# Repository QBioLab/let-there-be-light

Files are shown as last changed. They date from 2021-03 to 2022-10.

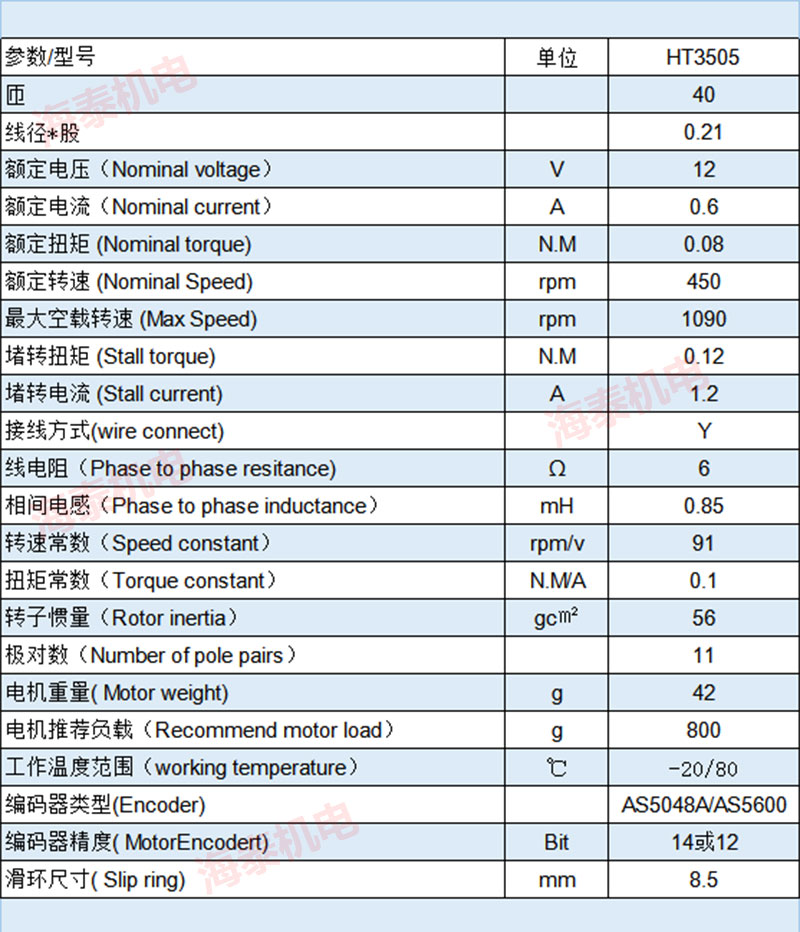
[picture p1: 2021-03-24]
Mechanism/datasheet/HT3505-2.jpg

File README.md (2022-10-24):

# Let there be light
Track and light mouse

## Control and Computing Unit with Khadas 控制和运算单元
Target: enable to remote controll, graph interface, error handle

Khadas VIM3 don't shop the kernel with usbtmc and i2c mux driver, so I
[rebuild kernel](https://docs.khadas.com/vim3/HowToUpgradeTheKernel.html)
inside [fenix's docker](https://github.com/khadas/fenix).
The usbtmc and i2c mux are package as module, I load [module automatic with systemd](https://wiki.archlinux.org/title/Kernel_module)
by add `usbtmc` and `i2c_mux_pca954x` to `/etc/modules-load.d/modules.conf`.

Only one USB bus is exported in VIM3, I try to use orignal M.2 port as PCI-e
port. I install ADT-Link's [M.2 NVMe to PCIe X1 extender](http://www.adtlink.cn/en/product/R41.html)
on Khadas M.2 extender board, then a PCIe Card(VIA VL805). The PCIe card is
power by sperated 5V. But system only reconginze this
card as USB2 bus. Why? May I also feed 12v pin. Once I mount USB3 device,
system will reboot. 

TODO: assign fixed camera path to specifical usb port. Device info could get
from `udevadm info -a -p  $(udevadm info -q path -n /dev/video0)`

TODO: organize output information
TODO: send command to power supply then release and return.

Build GUI in QT. 

Reference:
- [PyQtGraph library](https://github.com/pyqtgraph/pyqtgraph)
- [Assign fixed usb port name](https://www.freva.com/2019/06/20/assign-fixed-usb-port-names-to-your-raspberry-pi/)
- [How to bind v4l2 USB cameras to the same device names even after reboot?](https://unix.stackexchange.com/questions/77170/how-to-bind-v4l2-usb-cameras-to-the-same-device-names-even-after-reboot)
- [Convert M.2 to PCI-e in VIM3](https://forum.khadas.com/t/pci-e-card-power-supply/12122)
- [WiringPi-Python on VIM](https://docs.khadas.com/zh-cn/vim3/HowToUseWiringPi-Python.html)
- [Change Logo](https://docs.khadas.com/zh-cn/vim3/HowToChangeBootLogo.html)
- [Autostart login tty1 and execute command](https://unix.stackexchange.com/questions/44288/run-gui-application-on-startup)
- [renesas-UPD720201-usb3](https://pipci.jeffgeerling.com/cards_usb/renesas-UPD720201-usb3-6amlifestyle.html)

## Gimbal design and setting 云台设计
Before run SimpleBGC in khadas, please install `librxtx-java`

calibration design

```
|--------------------------|
| Camera & Gimbal Geometry |
|--------------------------|
|  O----> x                |
|  |                       |
| \|/     |--------|       |
|  y      | CAMERA |       |
|         |--------|       |
|                          |
|         |--------| +90   |
|         | GIMBAL | /|\   |
|         |--------|  |    |
|                0<---+yaw |
|--------------------------|
```

<<<<<<< HEAD
coordintiona transformation.
=======

>>>>>>> c09984db9b780412b9dba95ce789de024a3bc1f3

## Tracker Design
Color and movement

## ISSUSE & TODO 现存问题
+ offline test: gimbal rotate in preload sequence and saved video
+ add laser power switch in GUI
+ 微弱信号识别及过滤干扰目标: detect moving region
+ send poweroff command to motor after closing  
+ add force exit function, such as reboot?

## Ref 参考
https://superuser.com/questions/497933/50-usb-webcams-in-a-single-computer-is-that-really-possible

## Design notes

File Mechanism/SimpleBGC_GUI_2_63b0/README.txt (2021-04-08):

WINDOWS users: just run exe file

MAC OS users:  GUI uses a serial communication, that needs to create a lock file. 
To allow it, you should to do the following steps:
1. Start terminal (navigate to /Applications/Utilities and double click on Terminal)
2. Make folder "/var/lock" by command: sudo mkdir /var/lock
3. Change permissions by command: sudo chmod 777 /var/lock
4. Allow to run non-signed applications in  System Preferences > Security & Privacy > 
	General > Allow Applications downloaded from: Anywhere  (see http://d.pr/i/9fAm )

LINUX users: 
run.sh

ALL SYSTEMS: 

Special system drivers may be required. Check the recomendations of the seller of your board,
or try general drivers that may suit:
	
	FTDI http://www.ftdichip.com/Drivers/VCP.htm
	CP2102 http://www.silabs.com/products/mcu/pages/usbtouartbridgevcpdrivers.aspx

CONSOLE MODE

In this mode Java console is shown, that may be usefull for debugging
Start application by running script "run_console.bat" (or create similar script for your operating sysytem).

COMMAND-LINE MODE

There are several usefull commands that can be run in command-line mode (without opening the main interface window).
Execute "sbgc_cmd.bat" and it will print the usage prompt.

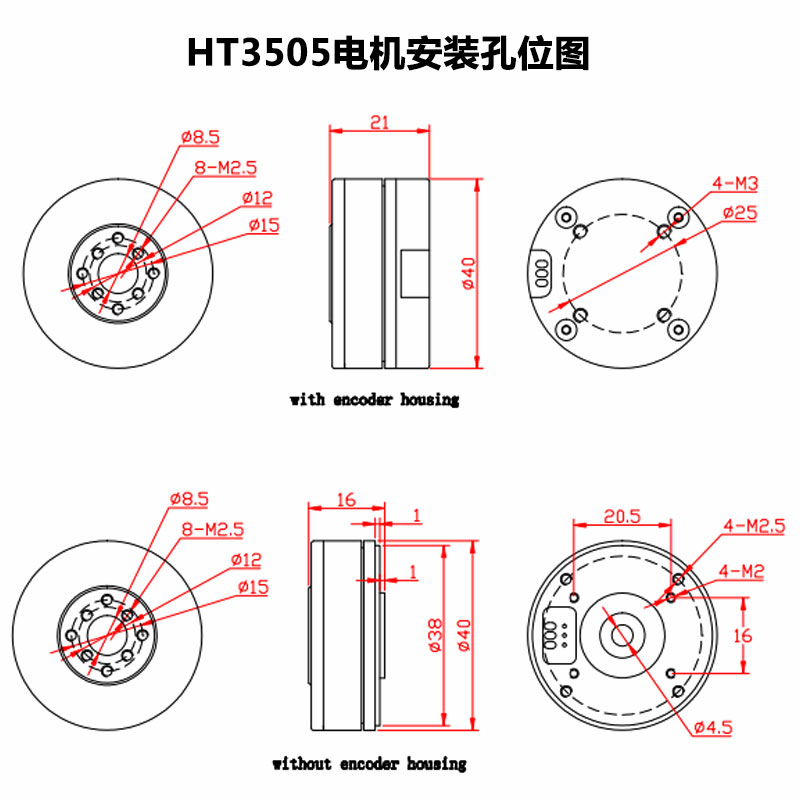
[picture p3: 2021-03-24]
Mechanism/datasheet/HT3505.jpg

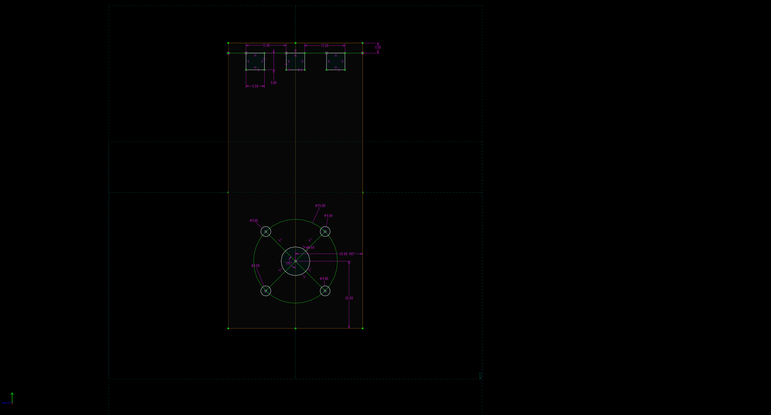
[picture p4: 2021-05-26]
Mechanism/gimbal-arm2-pitch.png

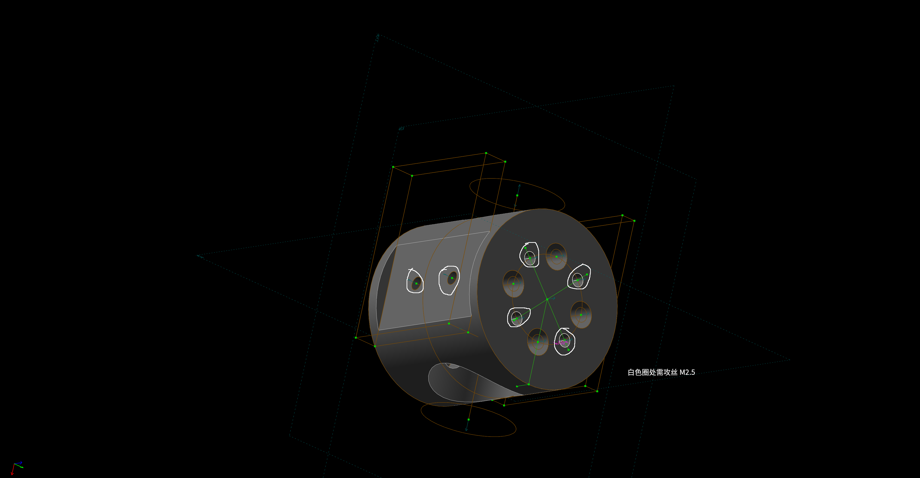
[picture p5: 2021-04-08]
Mechanism/CNC/gimbal-gun2-攻丝标注.png

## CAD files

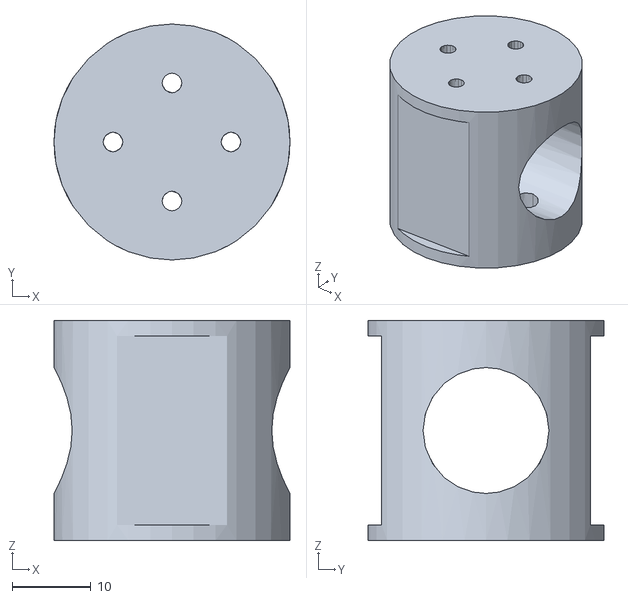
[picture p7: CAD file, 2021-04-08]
Mechanism/3d_printer/gimbal-gun2.stl
30.0 x 30.0 x 28.0

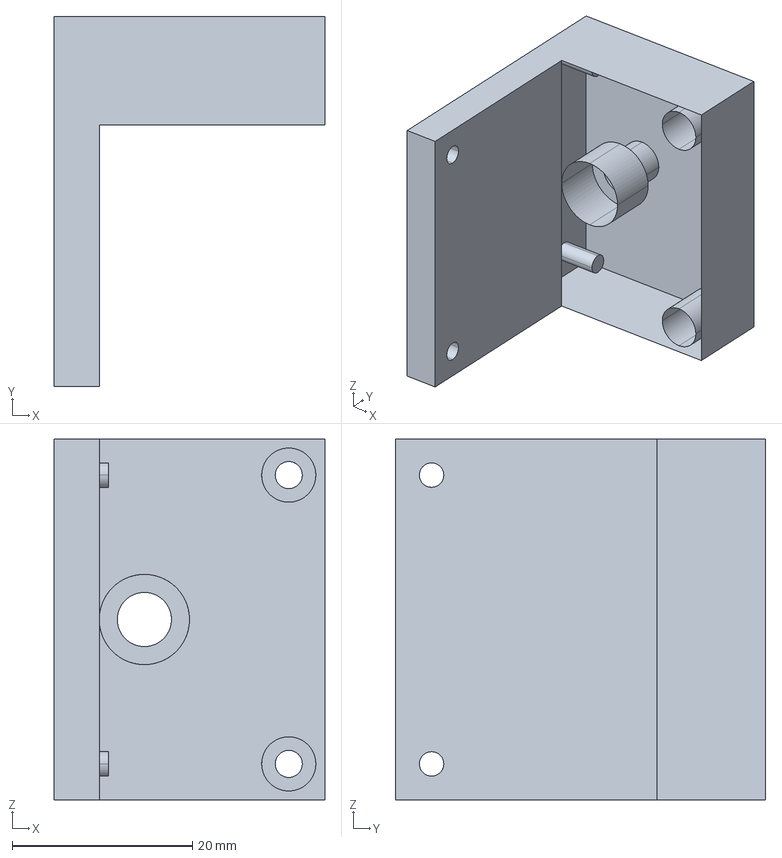
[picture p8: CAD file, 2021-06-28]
Mechanism/CNC/rightAngle.step
30.0 x 41.0 x 40.0 mm

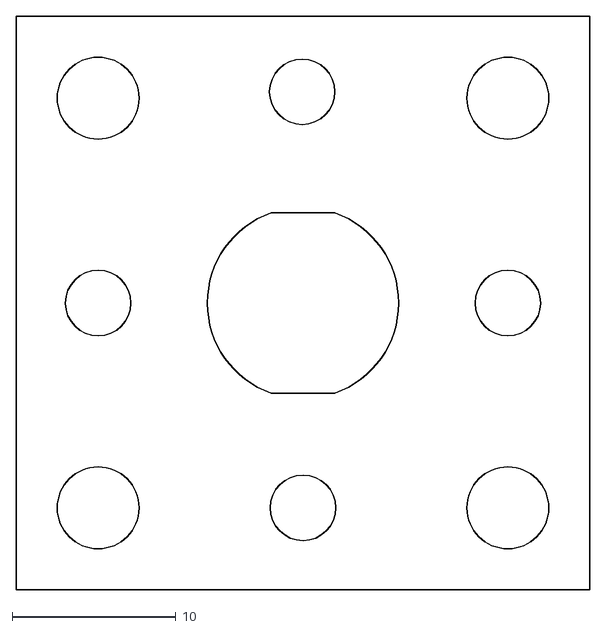
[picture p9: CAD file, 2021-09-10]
Mechanism/Cutting/PluginSet.dxf
35.0 x 35.0

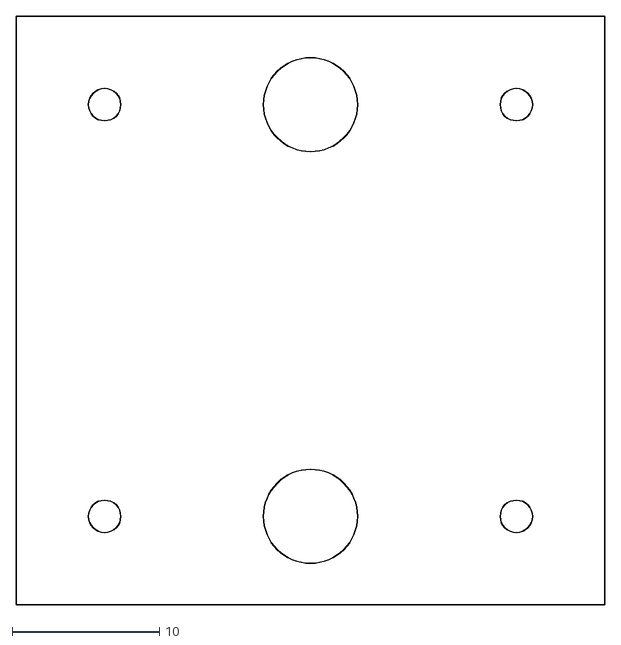
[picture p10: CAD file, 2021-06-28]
Mechanism/摄像头铝型材架.dxf
40.0 x 40.0

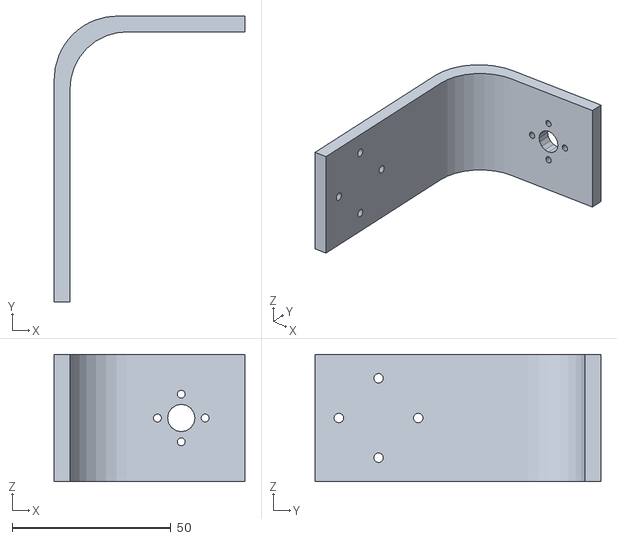
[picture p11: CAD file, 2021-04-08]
Mechanism/3d_printer/gimbal-arm.stl
60.0 x 90.0 x 40.0

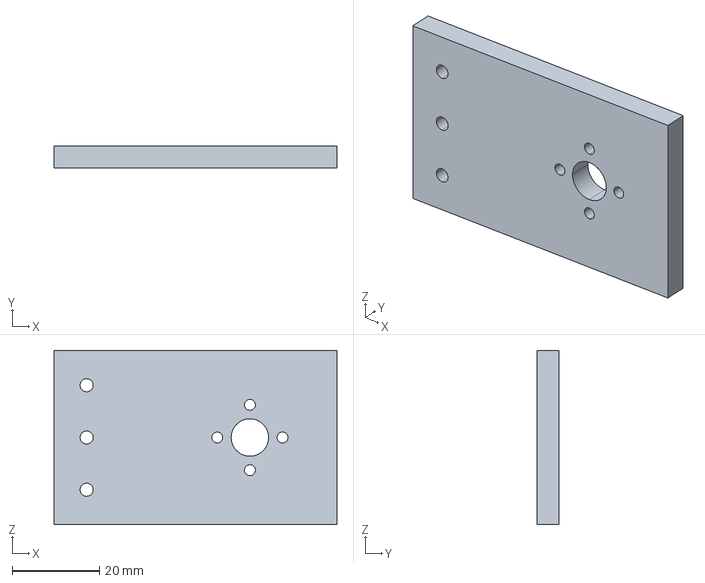
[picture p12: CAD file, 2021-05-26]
Mechanism/CNC/gimbal-arm-yaw-20210416.step
65.0 x 5.00 x 40.0 mm

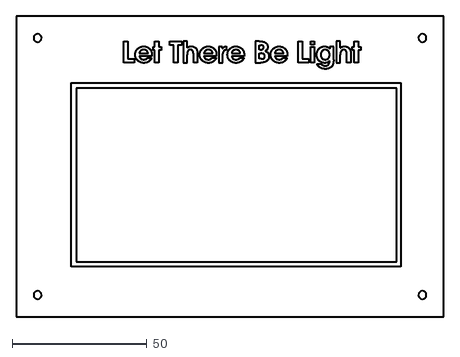
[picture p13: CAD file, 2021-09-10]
Mechanism/Cutting/TouchScreenSet.dxf
159.0 x 111.5

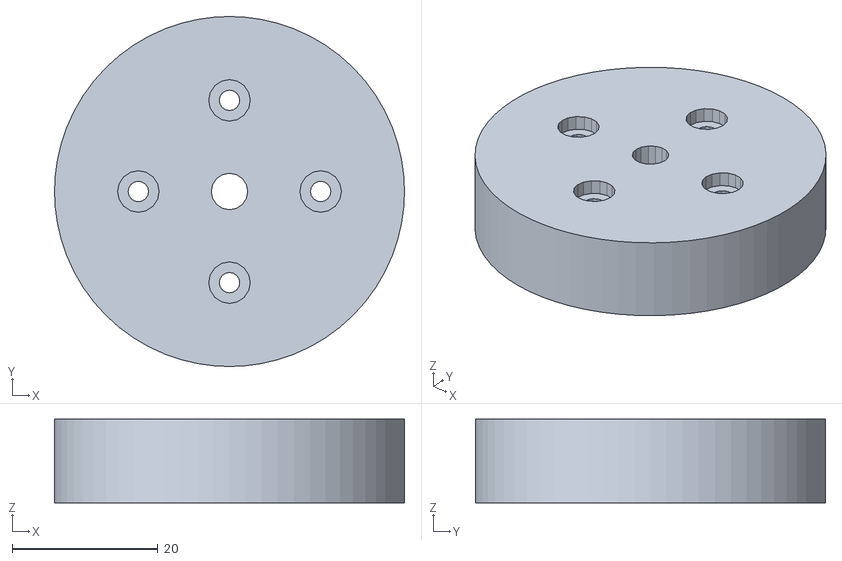
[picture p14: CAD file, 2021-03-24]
Mechanism/3d_printer/gimbal-header.stl
48.0 x 48.0 x 11.5

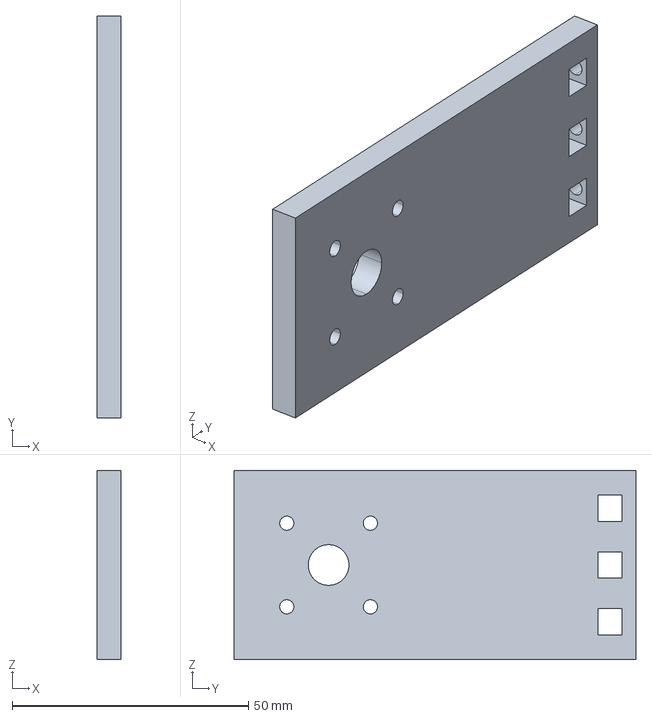
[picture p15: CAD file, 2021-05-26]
Mechanism/CNC/gimbal-arm2-pitch-20210427.step
5.00 x 85.0 x 40.0 mm

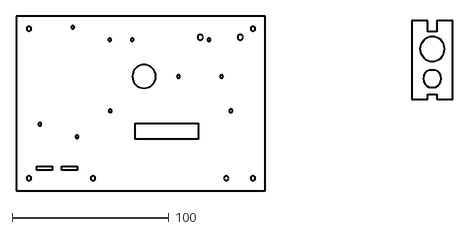
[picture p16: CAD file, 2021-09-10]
Mechanism/Cutting/ComputerCase.dxf
278.5 x 111.5

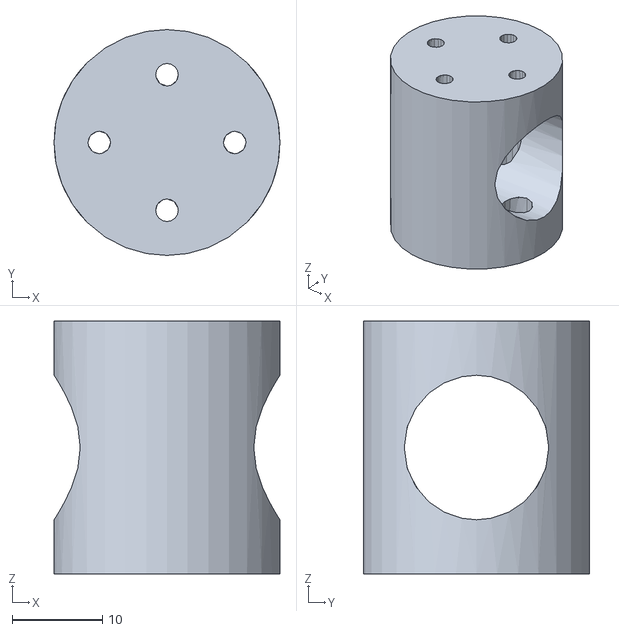
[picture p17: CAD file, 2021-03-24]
Mechanism/3d_printer/gimbal-gun.stl
25.0 x 25.0 x 28.0

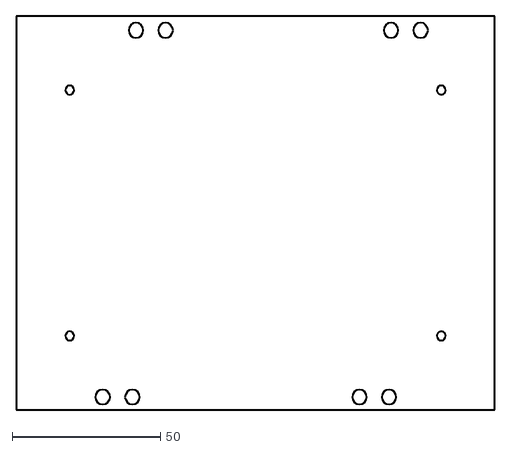
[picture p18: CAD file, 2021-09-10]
Mechanism/Cutting/powersupplysheet.dxf
161.5 x 133.0

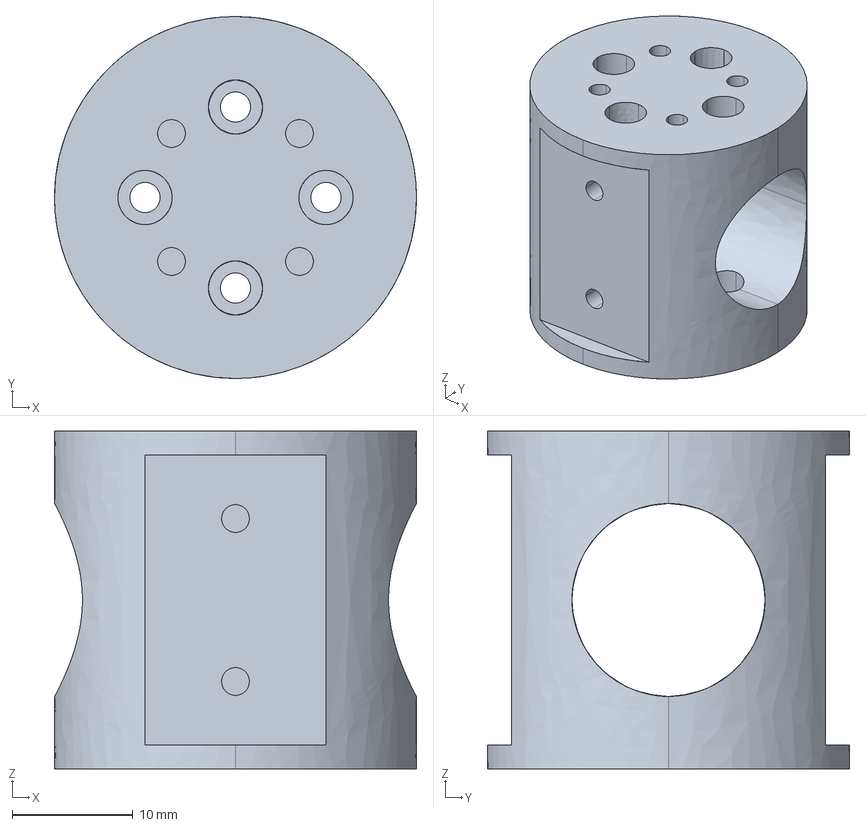
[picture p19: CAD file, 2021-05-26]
Mechanism/CNC/gimbal-gun2-20210416.step
30.0 x 30.0 x 28.0 mm

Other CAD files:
Mechanism/CNC/gimbal-arm-pitch-20210416.step
Mechanism/CNC/gimbal-header2-20210428.step
Mechanism/CNC/gimbal-header2-20210416.step
Mechanism/CNC/gimbal-gun2.step
Mechanism/CNC/gimbal-arm2.step
Mechanism/CNC/gimbal-header2.step

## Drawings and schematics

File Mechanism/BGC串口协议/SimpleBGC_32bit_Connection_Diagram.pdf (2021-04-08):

# BATTERY

# SimpleBGC 3.0 (32bit) connection diagram

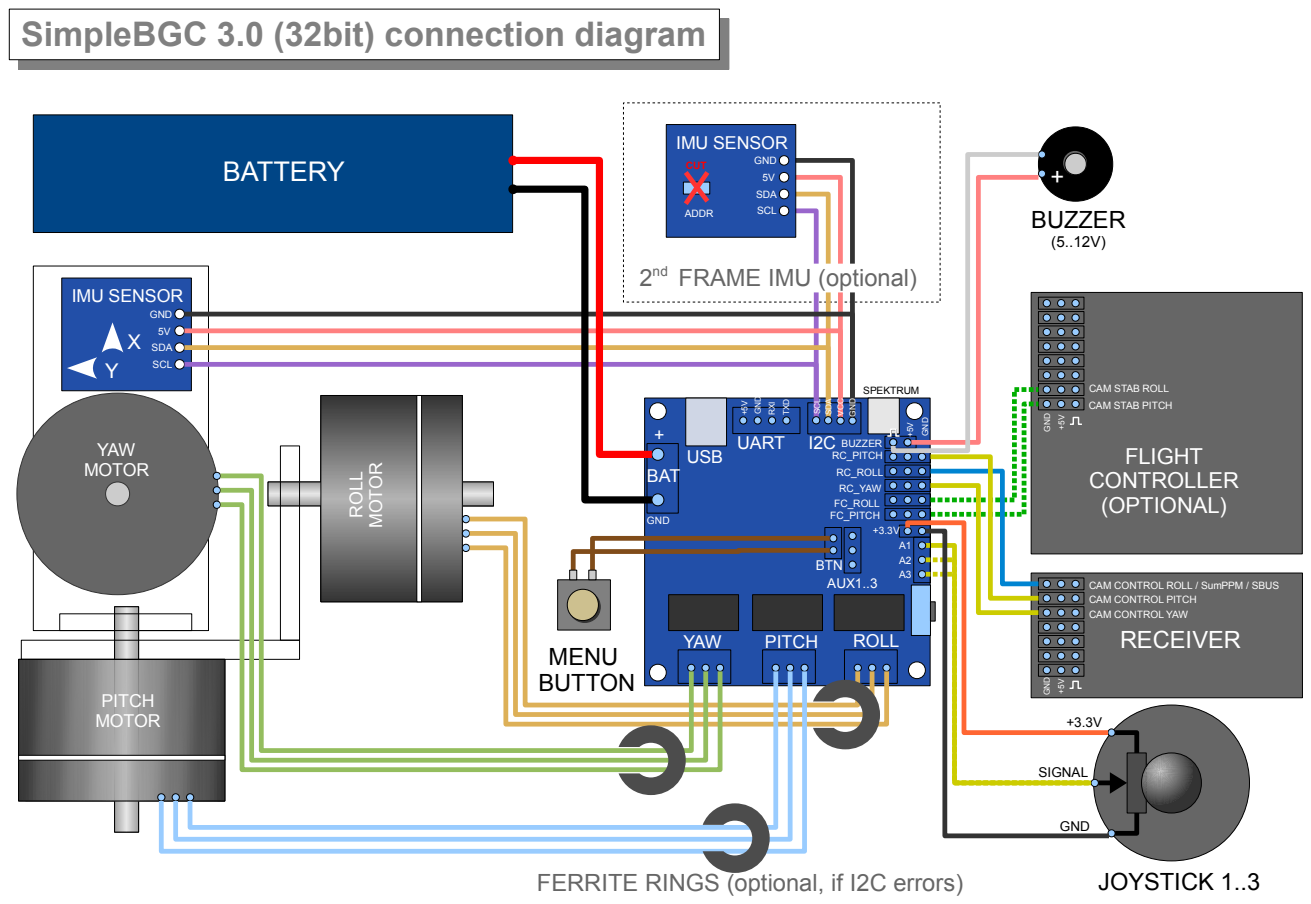
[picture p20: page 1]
UART; PITCH; ROLL; BAT; GND; FC_ROLL FC_PITCH; RC_ROLL; RC_PITCH; RXI; TXD; SCL; SDA; VCC; PITCH MOTOR; YAW MOTOR; IMU SENSOR; MENU BUTTON; JOYSTICK 1..3; SIGNAL; YAW; ADDR; CUT; BTN; RC_YAW; BUZZER; USB; AUX1..3; SPEKTRUM

nd FRAME IMU (optional)

CAM STAB ROLL
CAM STAB PITCH
FLIGHT
CONTROLLER
(OPTIONAL)

CAM CONTROL ROLL / SumPPM / SBUS
CAM CONTROL PITCH
CAM CONTROL YAW
RECEIVER

FERRITE RINGS (optional, if I2C errors)

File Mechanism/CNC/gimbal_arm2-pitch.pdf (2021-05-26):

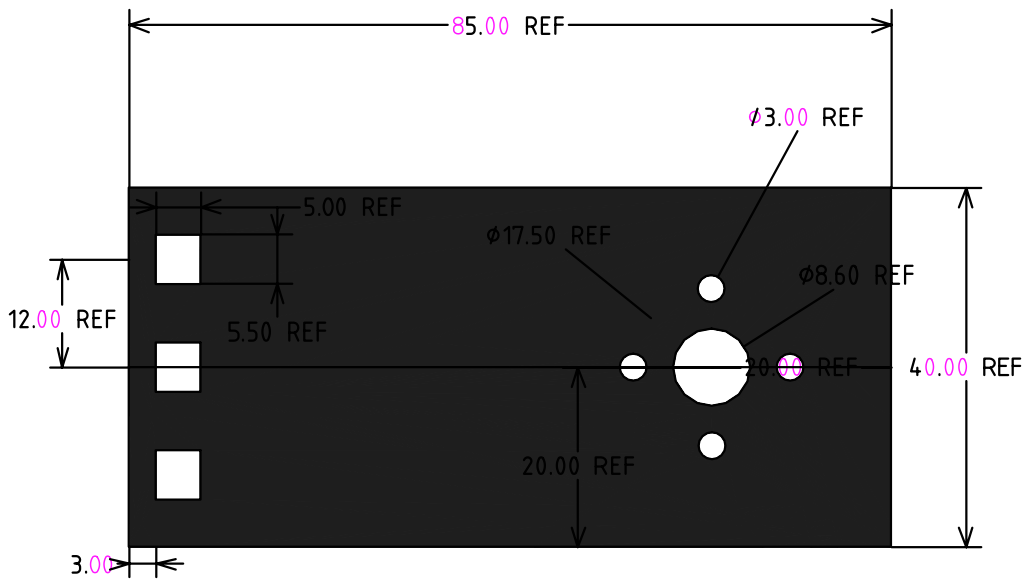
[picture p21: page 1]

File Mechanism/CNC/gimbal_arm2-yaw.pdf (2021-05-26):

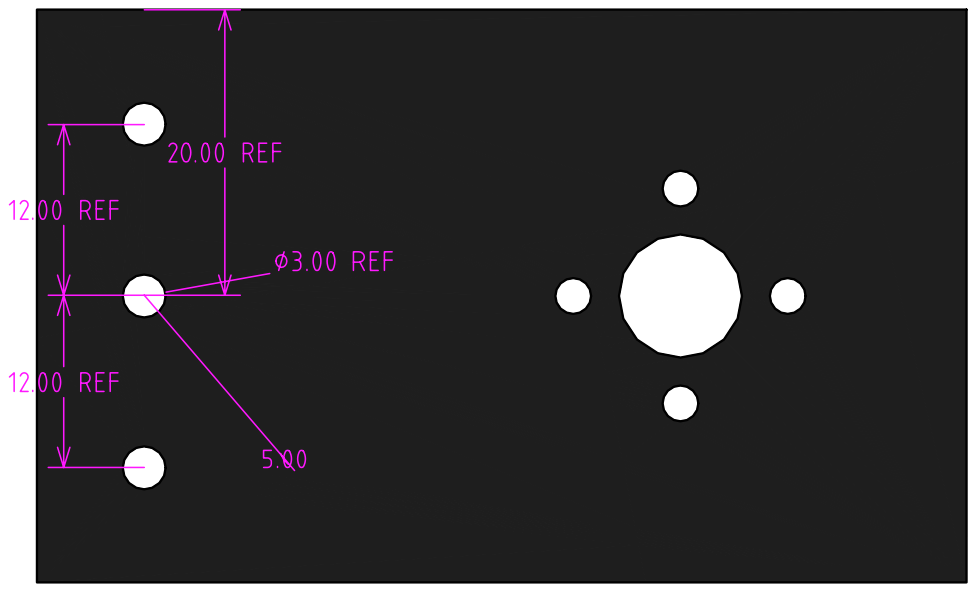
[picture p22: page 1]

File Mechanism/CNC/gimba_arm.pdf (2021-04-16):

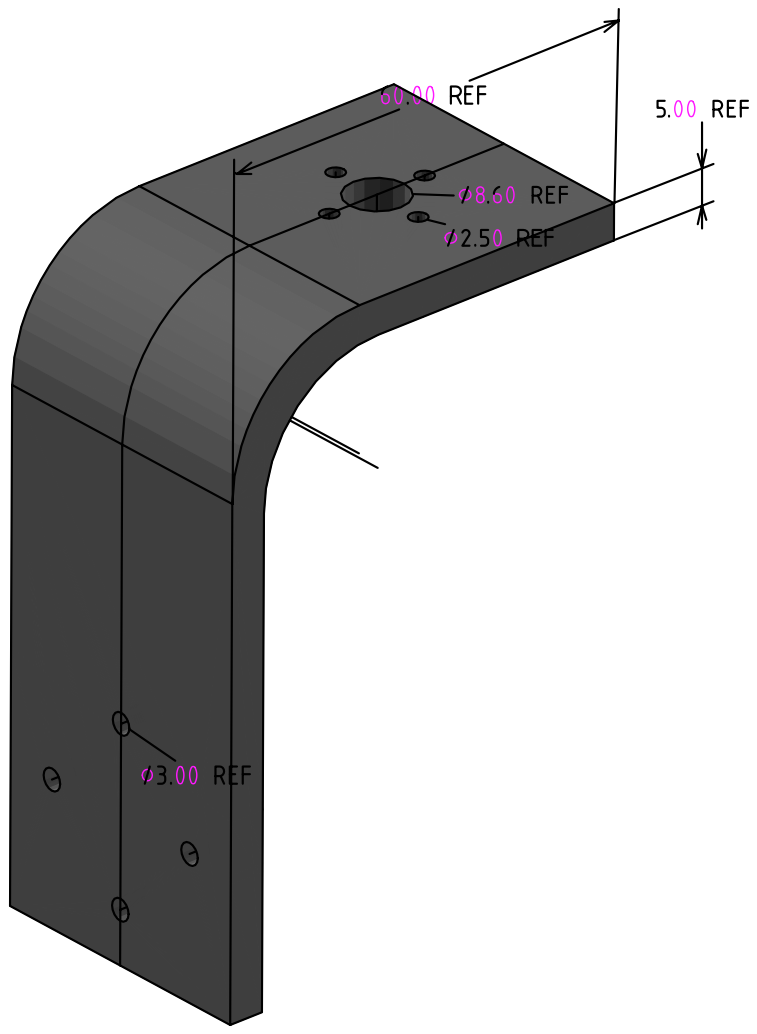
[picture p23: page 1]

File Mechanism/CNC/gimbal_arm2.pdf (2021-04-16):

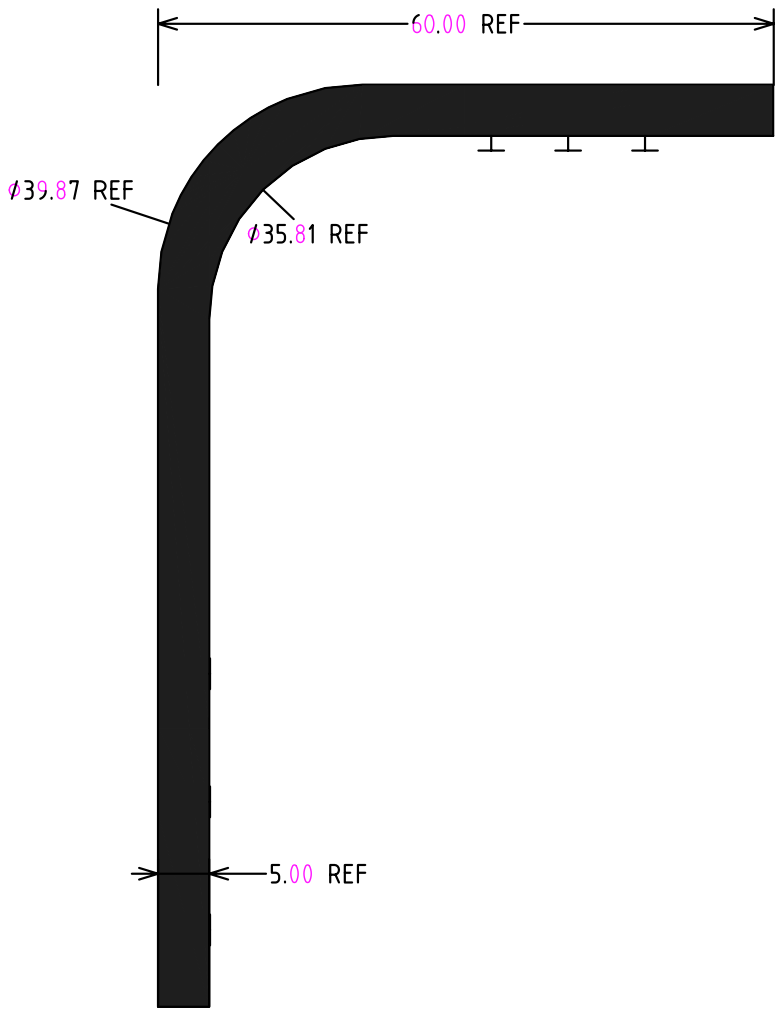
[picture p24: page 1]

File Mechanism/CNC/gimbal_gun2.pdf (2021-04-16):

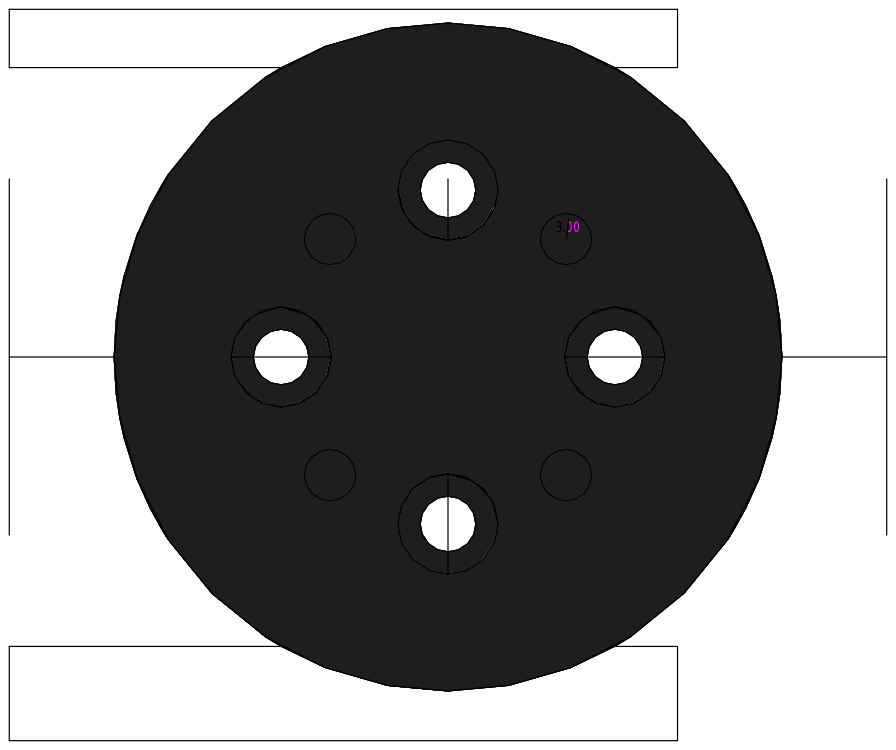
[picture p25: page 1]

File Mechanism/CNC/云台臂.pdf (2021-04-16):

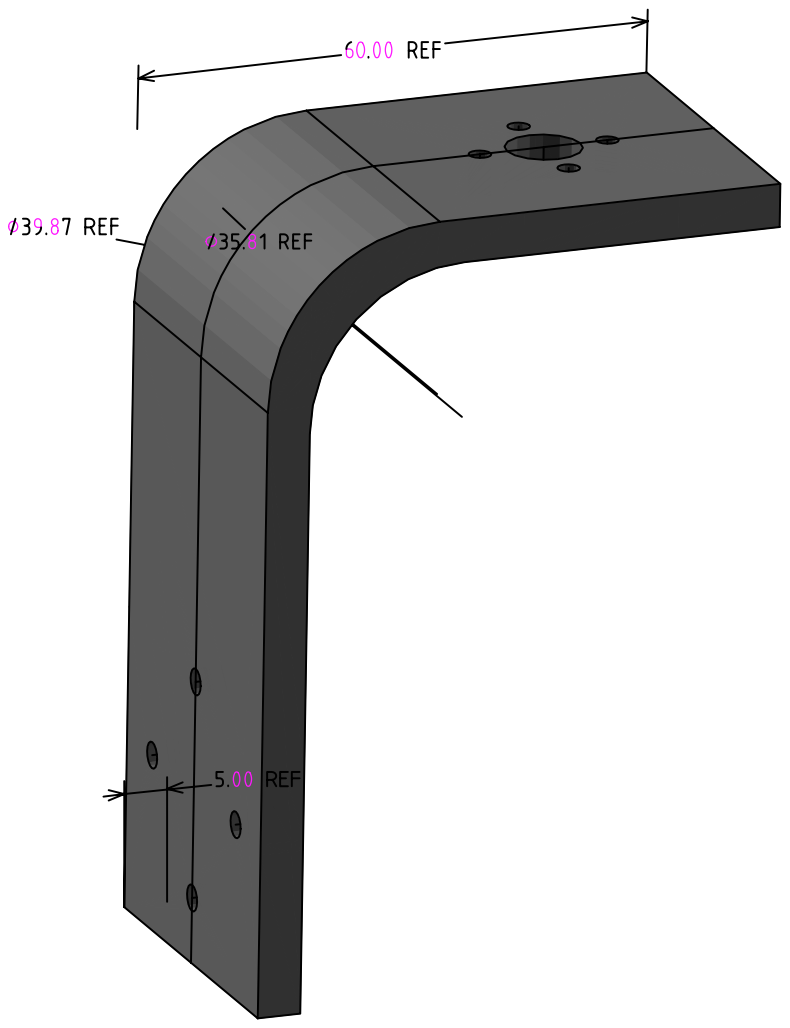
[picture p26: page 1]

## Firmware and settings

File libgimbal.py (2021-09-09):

import sys
import serial
import struct
from collections import namedtuple

"""
v0.1 first version
"""

# outgoing CMD_CONTROL - control gimbal movement
ControlData = namedtuple(
    'ControlData',
    'roll_mode pitch_mode yaw_mode roll_speed roll_angle \
     pitch_speed pitch_angle yaw_speed yaw_angle')
AngleData = namedtuple(
    'AngleData',
    'imu_roll_angle target_roll_angle target_roll_speed \
     imu_pitch_angle target_pitch_angle target_pitch_speed \
     imu_yaw_angle target_yaw_angle target_yaw_speed')
Message = namedtuple(
    'Message',
    'start_character command_id payload_size header_checksum \
    payload payload_checksum')

MOTOR_UNIT = 0.02197265625 # 720/32768


class gimbal:
    def __init__(self, PORT):
        self.PORT = PORT
        self.connected = False
        self.connect()
        
    def pack_control_data(self, control_data: ControlData) -> bytes:
        return struct.pack('<BBBhhhhhh', *control_data)

    def create_message(self, command_id: int, payload: bytes) -> Message:
        payload_size = len(payload)
        return Message(start_character=ord('>'),
              command_id=command_id,
              payload_size=payload_size,
              header_checksum=(command_id + payload_size) % 256,
              payload=payload,
              payload_checksum=sum(payload) % 256)

    def pack_message(self, message: Message) -> bytes:
        message_format = '<BBBB{}sB'.format(message.payload_size)
        return struct.pack(message_format, *message)


    def unpack_message(self, data: bytes, payload_size: int) -> Message:
        message_format = '<BBBB{}sB'.format(payload_size)
        return Message._make(struct.unpack(message_format, data))

    def read_message(self, connection: serial.Serial, payload_size: int) -> Message:
        # 5 is the length of the header + payload checksum byte
        # 1 is the payload size
        response_data = connection.read(5 + payload_size)
        #print('received response', response_data)
        return self.unpack_message(response_data, payload_size)

    def park_gimbal(self):
        self.rotate_gimbal(70, 0)

    def cal_motor_angle(self, angle):
        motor_angle = int(angle/MOTOR_UNIT)
        return motor_angle

    def rotate_gimbal(self, pitch_angle, yaw_angle):
        pitch_motor_angle = self.cal_motor_angle(pitch_angle)
        yaw_motor_angle = self.cal_motor_angle(yaw_angle)
        self.rotate_gimbal_in_motor_angle(pitch_motor_angle, yaw_motor_angle)

    def rotate_gimbal_in_motor_angle(self, pitch_motor_angle, yaw_motor_angle):
        CMD_CONTROL = 67
        control_data = ControlData(roll_mode=0, roll_speed=0, roll_angle=0,
                               pitch_mode=2, pitch_speed=32767, pitch_angle=pitch_motor_angle,
                               yaw_mode=5, yaw_speed=32767, yaw_angle=yaw_motor_angle)
        packed_control_data = self.pack_control_data(control_data)
        message = self.create_message(CMD_CONTROL, packed_control_data)
        packed_message = self.pack_message(message)
        self.connection.write(packed_message)
        # message = self.read_message(self.connection, 1)
        #print('received confirmation:', message)
        # print('confirmed command with ID:', ord(message.payload))

    def rotate_gimbal_rel(self, pitch_angle, yaw_angle):
        CMD_CONTROL = 67
        control_data = ControlData(roll_mode=0, roll_speed=0, roll_angle=0,
                               pitch_mode=5, pitch_speed=32767, pitch_angle=pitch_angle,
                               yaw_mode=5, yaw_speed=32767, yaw_angle=yaw_angle)
        packed_control_data = self.pack_control_data(control_data)
        message = self.create_message(CMD_CONTROL, packed_control_data)
        packed_message = self.pack_message(message)
        self.connection.write(packed_message)
        message = self.read_message(self.connection, 1)
        print('received confirmation:', message)
        print('confirmed command with ID:', ord(message.payload))

    def get_angles(self):
        CMD_GET_ANGLES = 73
        message = self.create_message(CMD_GET_ANGLES, b'')
        packed_message = self.pack_message(message)
        self.connection.write(packed_message)
        message = self.read_message(self.connection, 18) # 2*3*3
        return AngleData._make(struct.unpack('hhhhhhhhh', message.payload))

    def get_frame_heading_angle(self):
        """Get Frame Heading Angle
        |NUM_PARAMS 1u| PARAM_ID 1u|
        Uints: 1 degrees
        """
        CMD_GET_ADJ_VARS_VAL = 64
        FRAME_HEADING_ANGLE = 37
        message = self.create_message(CMD_GET_ADJ_VARS_VAL, 
                struct.pack('BB', 1, FRAME_HEADING_ANGLE))
        packed_message = self.pack_message(message)
        self.connection.write(packed_message)
        message = self.read_message(self.connection, 6) # 1u+1u+4b, 0.1 degrees
        data = struct.unpack('BBbbbb', message.payload) # eg. (1, 37, -1, 127, 0 ,0)
        return struct.unpack('BBbbbb', message.payload)
        #return (data[2]*1000 + (data[2]/abs(data[2]))*data[3])*0.1

    def set_frame_heading_angle(self, par1, par2, par3, par4):
        CMD_SET_ADJ_VARS_VAL = 31
        FRAME_HEADING_ANGLE = 37
        message = self.create_message(CMD_SET_ADJ_VARS_VAL, 
                struct.pack('BBbbbb', 1, FRAME_HEADING_ANGLE, par1, par2, par3, par4))
        packed_message = self.pack_message(message)
        self.connection.write(packed_message)
        message = self.read_message(self.connection, 1) 
        print('confirmed command with ID:', ord(message.payload))

    def connect(self):
        if self.connected == False:
            try:
                self.connection = serial.Serial(self.PORT, baudrate=115200, timeout=10)
                self.connected = True
            except Exception as error:
                print("Serial error, please check serial port")
                print("Detail: ", error)
                sys.exit()

    def disconnect(self):
        if self.connected == True:
            self.connection.close()
            self.connected = False
            print("Disconnect gimbal")

if __name__ == '__main__':
    gimbal_serial_name = "/dev/ttyGIMBAL1"
    if len(sys.argv) == 2 :
        gimbal_serial_name = sys.argv[1]
    gimbal_run = gimbal(gimbal_serial_name)
    gimbal_run.park_gimbal()

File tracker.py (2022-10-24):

import os
import time
import cv2 as cv
import numpy as np

"""
detecte mouse and laser point
V0.1 orignal work by zhangyi
V0.2 package to class
"""

FAIL = 0 # lost camera connection
MOVE = 1 # apply track
PARK = 2 # park pointer
LOST = 3 # lost mouse
IGNO = 4 # ignore tracking result

class MouseTracker:
    def __init__(self, camera_addr, roi):
        # initialize camera
        self.camera_addr = camera_addr
        try:
            self.camera = cv.VideoCapture(self.camera_addr)
        except Exception as error:
            print("Fail to open camera", self.camera_addr,":", error)
        # use MJPG to low cost of USB bandwidth 
        # ref: https://github.com/opencv/opencv/issues/9540
        self.camera.set(cv.CAP_PROP_FRAME_WIDTH, 640)
        self.camera.set(cv.CAP_PROP_FRAME_HEIGHT, 480)
        self.camera.set(cv.CAP_PROP_FPS, 25)
        self.camera.set(cv.CAP_PROP_AUTO_EXPOSURE, 1) # 1 for manual mode
        self.camera.set(cv.CAP_PROP_EXPOSURE, 100)
        #cam.set(cv.CAP_PROP_AUTO_WB, 0)
        fourcc = cv.VideoWriter_fourcc(*"MJPG")
        self.camera.set(cv.CAP_PROP_FOURCC, fourcc)
        # initialize video recorder
        self.save_moive = False
        self.save_fps = 5
        self.save_dir = "/dev/null"
        self.roi = roi  #[y0, y1, x0, x1]
        self.erode1 = 5
        self.centroid_y = self.centroid_x = 0
        self.last_centroid_y = self.last_centroid_x = 0
        self.count = 0
        self.last_time= time.time()

    def detecte_laser(self, frame):
        blue_mask = cv.inRange(frame, (0, 0, 220), (255, 255, 255)) 
        #return centroid_blue_x, centroid_blue_y

    def mask_red(self, hsv_frame):
        """HSV 遮罩"""
        hsv_h_range = [0, 10, 156, 180]
        hsv_s_range = [100, 250]
        hsv_v_range = [50, 200]
        lower_hsv0 = np.array([hsv_h_range[0], hsv_s_range[0], hsv_v_range[0]])
        upper_hsv0 = np.array([hsv_h_range[1], hsv_s_range[1], hsv_v_range[1]])
        lower_hsv1 = np.array([hsv_h_range[2], hsv_s_range[0], hsv_v_range[0]])
        upper_hsv1 = np.array([hsv_h_range[3], hsv_s_range[1], hsv_v_range[1]])
        mask0 = cv.inRange(hsv_frame, lower_hsv0, upper_hsv0)
        mask1 = cv.inRange(hsv_frame, lower_hsv1, upper_hsv1)
        mask_red = mask0 + mask1
        return mask_red

    def set_mask_red(self):
        """Set mask parameters"""
        print("Set HSV filter parameters")
    
    def mask_red_bgr(self, procession):
        """BGR 遮罩"""
        lower_bgr = np.array([90, 110, 180])
        upper_bgr = np.array([120, 150, 240])
        mask_red_bgr = cv.inRange(procession, lower_bgr, upper_bgr)
        return mask_red_bgr

    def set_erode1(self, erode1):
        self.erode1 = erode1

    def morphology_process(self, mask, erode1):
        """形态学处理"""
        morphology = cv.erode(mask, cv.getStructuringElement(cv.MORPH_ELLIPSE, \
                (self.erode1, self.erode1)))
        morphology = cv.dilate(morphology, cv.getStructuringElement(cv.MORPH_ELLIPSE, (30, 30)))
        morphology = cv.erode(morphology, cv.getStructuringElement(cv.MORPH_ELLIPSE, (20, 20)))
        morphology = cv.dilate(morphology, cv.getStructuringElement(cv.MORPH_ELLIPSE, (10, 10)))
        return morphology

    def track_mouse(self):
        """track red spot on mouse frame by frame
        return: result, position, image 
        """
        ret, frame = self.camera.read()
        if not ret:
            return FAIL, None, None
        #[y0:y1, x0:x1]
        procession = frame[self.roi[0]: self.roi[1], self.roi[2]: self.roi[3]]
        self.save_data(procession)

        #HSV 遮罩
        hsv_frame = cv.cvtColor(procession, cv.COLOR_BGR2HSV)
        mask = self.mask_red(hsv_frame)
        if np.all(mask == 0):
            self.count = self.count + 1
            print('mask = None', self.count)
            if self.count >= 5000:
                self.count = 0
                #return PARK, None, procession
            return LOST, None, procession

        #形态学处理
        morphology = self.morphology_process(mask, self.erode1)
        if np.all(morphology == 0):
            self.count = self.count + 1
            print('morphology = None', self.count)
            if self.count >= 5000:
                self.count = 0
                #return PARK, None, procession
            return LOST, None, procession

        #画轮廓
        contour, hierarchy = cv.findContours(morphology, cv.RETR_CCOMP,\
                cv.CHAIN_APPROX_NONE)
        if len(contour) == 0:
            self.count = self.count + 1
            print('contour = None', self.count)
            if self.count >= 5000:
                self.count = 0
                #return PARK, None, procession
            return LOST, None, procession

        #找质心
        moment = cv.moments(contour[-1])
        if moment['m00'] == 0:
            self.count = self.count + 1
            print('contour = Open', self.count)
            if self.count >= 5000:
                self.count = 0
                #return PARK, None, procession
            return LOST, None, procession
        self.centroid_x = round(moment['m10'] / moment['m00'])  
        self.centroid_y = round(moment['m01'] / moment['m00']) 

        #畫跟蹤點
        self.count = 0
        centroid_BGR = (0, 0, 255)
        centroid_result = cv.circle(procession, (self.centroid_x, self.centroid_y), 5, centroid_BGR, -1)
        #print("Found mouse at:", self.centroid_x, self.centroid_y)
        dist_movement = np.sqrt(np.square(self.last_centroid_x - self.centroid_x) \
            + np.square(self.last_centroid_y - self.centroid_y))
        if dist_movement > 0:
            self.last_centroid_x = self.centroid_x
            self.last_centroid_y = self.centroid_y
            return MOVE, [self.centroid_x + self.roi[2], 
                self.centroid_y + self.roi[0]], centroid_result
            #print(self.centroid_x, self.centroid_y)
            #return MOVE, [self.centroid_x, self.centroid_y], centroid_result
        return IGNO, None, centroid_result

    def set_data_dir(self, directory):
        record_time = time.strftime("%Y%m%d-%H%M", time.localtime())
        self.save_moive = True
        self.save_dir = directory
        fourcc = cv.VideoWriter_fourcc(*"MJPG")
        height = self.roi[1] - self.roi[0]
        width = self.roi[3] - self.roi[2]
        self.check_dir(directory)
        self.out = cv.VideoWriter(self.save_dir+"/record-"+str(self.camera_addr)\
            +"-"+record_time+".mkv", fourcc, self.save_fps, (width, height))

    def check_dir(self, directory):
        if not os.path.exists(directory):
            os.makedirs(directory)
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

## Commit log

2021-01-26 fix coordination map and servo vibration
    [fireball.py]
2021-03-24 upload gimbal mechanism design
    [L.stl, gimbal-gun.stl, gimbal-header.stl]
2021-04-08 upload CNC file
    [L.stl, SimpleBGC 32bit board.cfg, gimbal-arm.stl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]
2021-04-16 updaete mechanism design
    [gimbal-arm2.step]
2021-05-26 upload case for Khadas VIM3
2021-05-26 upload mechanism files
    [gimbal-arm-pitch-20210416.step, gimbal-arm-yaw-20210416.step, gimbal-arm2-pitch-20210427.step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]
2021-06-24 add timer to control dp832 power supply
2021-06-28 update mechanism file
    [gimbal-arm2-pitch-20210427.step, gimbal-arm2.step, gimbal-gun2.step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]
2021-07-01 fix bug: scheduler will work based on init state
    [mouseGUI.py]
2021-09-09 udev file to fixed camera and gimbal serial name
2021-09-09 set camera frame rate
2021-09-09 yaw rotate in -90 to 90 to avoid over-rotation
    [pointer.py]
2021-09-09 auto find gimbal position in camera view
2021-09-09 park pitch in 70 degree to avoid yaw's random rotation
    [libgimbal.py]
2021-09-09 park pitch at 70 degree instead of 90 degree when pitch over limit
2021-09-10 upload khadas case and plugset
    [ComputerCase.dxf, PluginSet.dxf, TouchScreenSet.dxf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]
2021-12-11 fix bug: divide to zero
    [pointer.py]
